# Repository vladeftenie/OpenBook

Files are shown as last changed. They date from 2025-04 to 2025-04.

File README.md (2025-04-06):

# OpenBook ESP32-C6 Complete Hardware Guide

## Overview
The OpenBook is an e-reader built around the ESP32-C6 chip. It uses an e-paper screen (like Kindle), has an SD card slot for books, can check room temperature and air quality, and has a battery that lasts a long time. It connects to Wi-Fi and Bluetooth so you can download books and update it.

## Main Parts

### Brain: ESP32-C6-WROOM-1-N8
- **What It Does**: Controls everything in the device
- **Architecture**: RISC-V (Single-Core)
- **Wireless**: Wi-Fi 6, Bluetooth 5 LE
- **Power Needs**: 3.3V
- **How It Talks**: SPI, I²C, UART, GPIO, USB

## Display Details

### E-Paper Screen
- **How It Connects**: SPI (shares wires with SD card)
- **Wires**:
  - Select Wire (EPD_CS): `GPIO 10`
  - Command Wire (EPD_DC): `GPIO 5`
  - Reset Wire: `GPIO 23`
  - Busy Signal: `GPIO 3`
  - Data Wires: shared with SD card
- **Screen Size**: 1404 × 1872 pixels (6.8")

## Memory Options

### SD Card Slot
- **How It Connects**: SPI
- **Wires**:
  - Select Wire (SS_SD): `GPIO 4`
  - Data Out (MOSI): `GPIO 7`
  - Data In (MISO): `GPIO 27`
  - Clock (SCK): `GPIO 6`
- **Space**: Works with cards up to 32GB

### Built-in Flash Memory (64MB)
- **How It Connects**: SPI (shared)
- **Wires**:
  - Select Wire (FLASH_CS): `GPIO 12`
  - Shared: `MOSI`, `MISO`, `SCK`
- **What It Stores**: System files, fonts, and some books
- **Chip Used**: W25Q512JVEIQ (Winbond)

## Power System

### Power Supply
- **Gets Power From**: USB-C (5V)
- **Gives Power At**: 3.3V using a voltage regulator
- **Battery**: 3.7V Li-Po, 2000mAh

### Charging System
- **What It Does**: Charges the Li-Po battery
- **Charging Speed**: 500mA
- **Chip Used**: MCP73831T-2ACI-OT (Microchip)

### Battery Monitor
- **What It Does**: Checks battery level and voltage
- **How It Connects**: I²C
- **Chip Used**: MAX17048G+T10 (Analog Devices)

### Backup Power
- **What It Does**: Keeps critical parts running during battery swaps
- **Part Used**: CPH3225A supercapacitor (Seiko)

## Sensors

### Air Quality Sensor – BME688
- **What It Measures**: Temperature, humidity, air pressure, gas levels
- **How It Connects**: I²C (shares wires with clock)
- **Power Needs**: 3.3V
- **Power Control Wire**: `GPIO 17`

### Clock Chip – DS3231SN
- **What It Does**: Keeps accurate time even when powered off
- **How It Connects**: I²C
- **Wires**:
  - Clock Wire (SCL): `GPIO 20`
  - Data Wire (SDA): `GPIO 19`
  - Alert Wire (INT): `GPIO 8`
  - Timing Wire (32KHz): `GPIO 9`
  - Reset Wire: `GPIO 16`
- **How Accurate**: About 1 minute off per year

## Connecting to Other Things

### USB-C Port
- **What It Does**: Charges the device and transfers data
- **Data Wires**:
  - USB_D-: `GPIO 13`
  - USB_D+: `GPIO 14`
- **Protection**: Has surge protection (USBLC6-2SC6Y chip)

### Expansion Port (Qwiic / Stemma QT)
- **What It Does**: Lets you add other sensors or devices
- **How It Connects**: I²C
- **Power Out**: 3.3V
- **Wires**: Uses the same I²C wires as other parts

## User Buttons
- **Boot Button**: Connected to `GPIO 15` (changes boot mode)
- **Reset Button**: Connected to pin 3 (restarts device)
- **Mode Button**: Connected to `GPIO 23` (changes display modes)

## Protection Features
- Surge protectors on USB and other wires
- Protection against putting batteries in backward
- Static electricity protection

## How Parts Connect

| Pin Number | What It Does | Connects To | More Info |
|---|---|---|---|
| 3 | RESET | Reset Button | Restarts the whole system |
| 4 | SS_SD | SD Card (pin 2) | Selects the SD card for talking |
| 6 | SCK | SD Card (pin 5) | Clock beat for data timing |
| 7 | MOSI | SD Card (pin 3) | Sends data out to SD card |
| 8 | INT_RTC | Clock Chip (pin 3) | Gets alerts from the clock |
| 9 | 32KHz | Clock Chip (pin 1) | Gets timing signal from clock |
| 13 | USB_D- | USB-C Port (pin 3) | USB negative data wire |
| 14 | USB_D+ | USB-C Port (pin 1) | USB positive data wire |
| 15 | IO/BOOT | Boot Button | Selects startup mode |
| 16 | RTC_RST | Clock Chip (pin 4) | Resets the clock chip |
| 17 | I2C_PW | Air Sensor (pins 6, 8, 2) | Controls power to air sensor |
| 19 | SDA | Multiple devices | Shared data wire for I²C |
| 20 | SCL | Multiple devices | Shared clock wire for I²C |
| 23 | IO/CHANGE | Mode Button | Changes display/device mode |
| 27 | MISO | SD Card (pin 7) | Gets data from SD card |

## How It All Connects
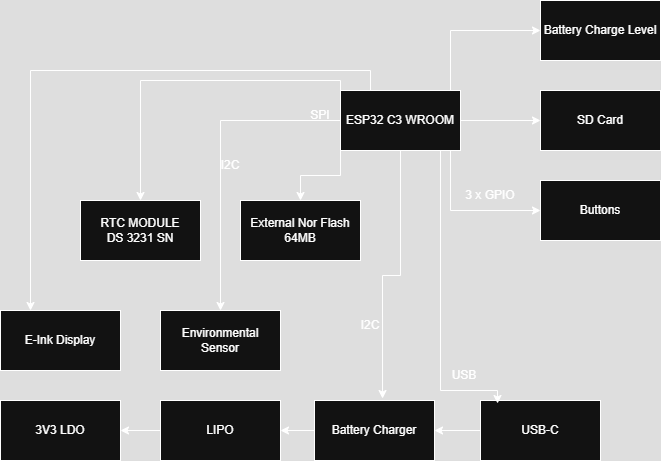
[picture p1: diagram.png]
Circuit Diagram


## BOM

| Component | Link | Estimated Price |
|---|---|---|
| R1_PINH1, R2-PINH1, R_BOOT, R_CHARGE, R_CL1, R_RESET | https://componentsearchengine.com/part-view/R0402%201%25%20100%20K%20(RC0402FR-07100KL)/YAGEO | €0.01 (per unit) |
| R1, R1-PINH, R2-PINH, R4, R5, R6, R7, R8, R9, R10 | https://componentsearchengine.com/part-view/R0402%201%25%20100%20K%20(RC0402FR-07100KL)/YAGEO | €0.01 (per unit) |
| C5 | https://componentsearchengine.com/part-view/CC0402MRX5R5BB106/YAGEO | €0.10 |
| EPD_C1, EPD_C2, EPD_C5, EPD_C6, EPD_C7, EPD_C8, EPD_C9, EPD_C10, EPD_C11, EPD_C12 | https://componentsearchengine.com/part-view/CC0402MRX5R5BB106/YAGEO | €0.10 (per unit) |
| R2 | https://componentsearchengine.com/part-view/R0402%201%25%20100%20K%20(RC0402FR-07100KL)/YAGEO | €0.01 |
| R1_BAT | https://componentsearchengine.com/part-view/R0402%201%25%20100%20K%20(RC0402FR-07100KL)/YAGEO | €0.01 |
| U4 | https://www.snapeda.com/api/url_track_click_mouser/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 | €3.80 |
| J2 | https://componentsearchengine.com/part-view/USB4110-GF-A/GCT%20(GLOBAL%20CONNECTOR%20TECHNOLOGY) | €0.95 |
| D1 | https://www.snapeda.com/parts/USBLC6-2SC6Y/STMicroelectronics/view-part/?ref=eda | €0.60 |
| U1 | https://www.snapeda.com/parts/W25Q512JVEIQ/Winbond+Electronics/view-part/?ref=eda | €4.20 |
| D3, D4, D5 | https://www.snapeda.com/api/url_track_click_mouser/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 | €0.40 (per unit) |
| D6, D8, D9, D10, D11, D12 | https://www.snapeda.com/api/url_track_click_mouser/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 | €0.30 (per unit) |
| J3 | https://www.digikey.ro/en/models/926710 | €1.05 |
| C1_BAT, C1_BAT1, C1_BAT2, C2_BAT, C5_USB | https://componentsearchengine.com/part-view/CC0402MRX5R5BB106/YAGEO | €0.10 (per unit) |
| C4 | https://componentsearchengine.com/part-view/CC0402MRX5R5BB106/YAGEO | €0.10 |
| R2-USB, R2-USB1 | https://componentsearchengine.com/part-view/R0402%201%25%20100%20K%20(RC0402FR-07100KL)/YAGEO | €0.01 (per unit) |
| C1, C2, C4_USB, C6, C7, C8, C9, C10, C_DELAY | https://componentsearchengine.com/part-view/CC0402MRX5R5BB106/YAGEO | €0.10 (per unit) |
| C3 | https://a360.co/4iZy6AA | €0.12 |
| J4 | https://store.comet.srl.ro/Catalogue/Product/43497/ | €0.35 |
| R_CAPACITOR | https://componentsearchengine.com/part-view/R0402%201%25%20100%20K%20(RC0402FR-07100KL)/YAGEO | €0.01 |
| R2_BAT | https://componentsearchengine.com/part-view/R0402%201%25%20100%20K%20(RC0402FR-07100KL)/YAGEO | €0.01 |
| TP1, TP2, TP3, TP4, TP5, TP6, TP7, TP8, TP9, TP10, TP11, TP12, TP13, TP14, TP15, TP16, TP17 | https://grabcad.com/library/test-points-printed-circuit-board-1 | €0.02 (per unit) |
| U2 | https://www.snapeda.com/parts/ESP32-C6-WROOM-1-N8/Espressif+Systems/view-part/?ref=eda | €4.50 |
| PFMF.050.1 | https://www.mouser.co.uk/ProductDetail/EPCOS-TDK/B72520T0350K062?qs=dEfas%2FXlABIszF52uu7vrg%3D%3D | €0.65 |
| CHG_LED | https://www.snapeda.com/parts/KP-1608SURCK/Kingbright/view-part/?ref=search&t=LED%200603 | €0.15 |
| SJ1 | https://grabcad.com/library/solder-jumpers-1 | €0.05 |
| SENSOR2 | https://www.snapeda.com/parts/BME680/Bosch/view-part/?welcome=home | €10.50 |
| MCP73831 | https://www.digikey.ro/en/products/detail/microchip-technology/MCP73831T-2ACI-OT/964301 | €0.75 |
| J1 | https://componentsearchengine.com/part-view/XC6220A331MR-G/Torex | €1.25 |
| R3 | https://componentsearchengine.com/part-view/R0402%201%25%20100%20K%20(RC0402FR-07100KL)/YAGEO | €0.01 |
| R1_PWRUSB | https://componentsearchengine.com/part-view/R0402%201%25%20100%20K%20(RC0402FR-07100KL)/YAGEO | €0.01 |
| IC4 | https://componentsearchengine.com/part-view/XC6220A331MR-G/Torex | €1.25 |
| L1 | https://eu.mouser.com/ProductDetail/Wurth-Elektronik/744043680?qs=PGXP4M47uW6VkZq%252BkzjrHA%3D%3D | €0.85 |
| IC1 | https://componentsearchengine.com/part-view/BD5229G-TR/ROHM%20Semiconductor | €1.20 |
| BOOT_BUTTON, CHANGE_BUTTON, RESET_BUTTON | https://www.snapeda.com/parts/EVQP7L01P/Panasonic/view-part/?ref=search&t=evqp7l | €0.25 (per unit) |
| C10_SUPERCAP | https://www.snapeda.com/api/url_track_click_mouser/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 | €2.50 |
| U3 | https://www.snapeda.com/api/url_track_click_mouser/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 | €8.95 |
| Q2 | https://componentsearchengine.com/part-view/DMG2305UX-7/Diodes%20Incorporated | €0.55 |
| Q1, Q3 | https://componentsearchengine.com/part-view/SI1308EDL-T1-GE3/Vishay | €0.45 (per unit) |
| D2, D7 | https://eu.mouser.com/ProductDetail/KYOCERA-AVX/SD0805S020S1R0?qs=jCA%252BPfw4LHbpkAoSnwrdjw%3D%3D | €0.30 (per unit) |

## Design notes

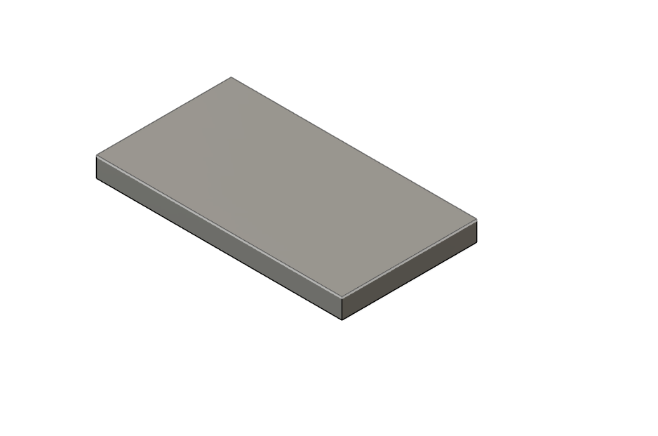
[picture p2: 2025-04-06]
Images/battery.png

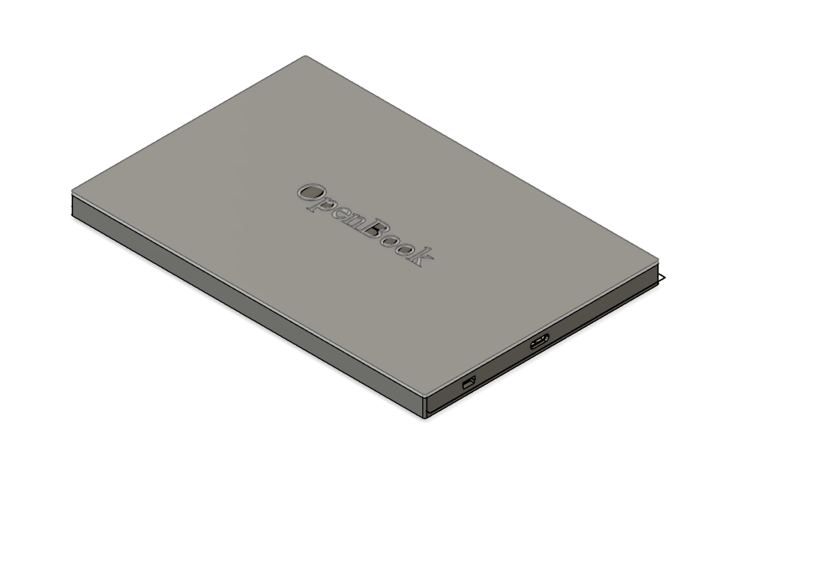
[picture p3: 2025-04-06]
Images/enclosure.png

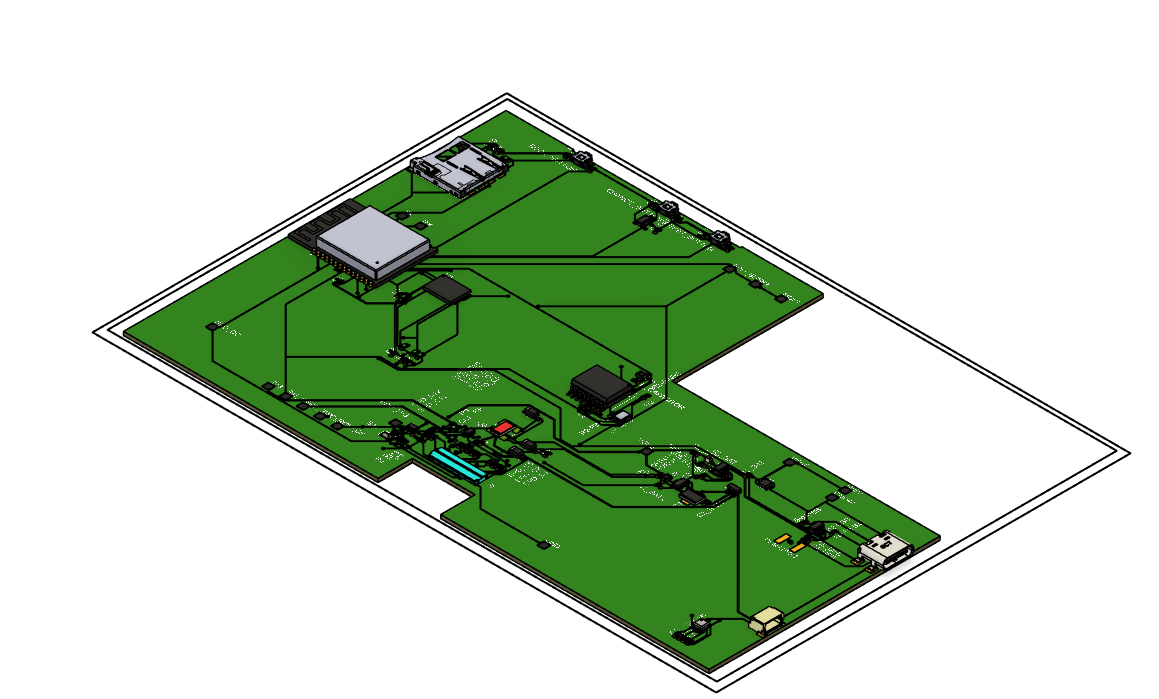
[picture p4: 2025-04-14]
Images/placuta.png

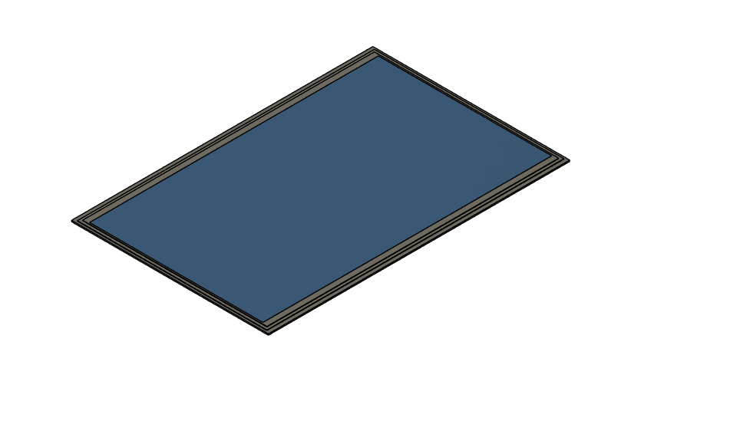
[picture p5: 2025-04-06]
Images/display.png

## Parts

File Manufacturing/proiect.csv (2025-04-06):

Qty | Value | Device | Package | Parts | Description | ARROW_PART_NUMBER | ARROW_PRICE-STOCK | AVAILABILITY | CENTROID_NOT_SPECIFIED | CHECK_PRICES | COPYRIGHT | DATASHEET | DESCRIPTION | DIGIKEY_DESCRIPTION | DIGIKEY_PART_NUMBER | HEIGHT | LEAD_FREE | MANUFACTURER_NAME | MANUFACTURER_PART_NUMBER | MF | MFR_NAME | MOUSER_PART_NUMBER | MOUSER_PRICE-STOCK | MOUSER_TESTING_PART_NUMBER | MOUSER_TESTING_PRICE-STOCK | MP | MPN | PACKAGE | POPULARITY | PREFIX | PRICE | PROD_ID | PURCHASE-URL | ROHS | SNAPEDA_LINK | SPICEMODEL | SPICEPREFIX | TEMPERATURE_RANGE_HIGH | TEMPERATURE_RANGE_LOW | TP_SIGNAL_NAME | VALUE
1 |  | ADAFRUIT_LEDCHIP-LED0603 | ADAFRUIT_CHIP-LED0603 | CHG_LED | LED
1 |  | SJ | SJ | SJ1 | SMD solder JUMPER |  |  |  |  |  |  |  |  |  |  |  |  |  |  |  |  |  |  |  |  |  |  |  | 3
1 | 0.1uF/50V | ESP32_WROVER_EAGLE-LTSPICE_CC0402 | ESP32_WROVER_EAGLE-LTSPICE_C0402 | EPD_C5 | CAPACITOR, European symbol |  |  |  |  |  |  |  |  |  |  |  |  |  |  |  |  |  |  |  |  |  |  |  |  |  |  |  |  |  |  | NONE | C
1 | 0.47 | ESP32_WROVER_EAGLE-LTSPICE_RR0402 | ESP32_WROVER_EAGLE-LTSPICE_R0402 | R3 | RESISTOR, European symbol |  |  |  |  |  |  |  |  |  |  |  |  |  |  |  |  |  |  |  |  |  |  |  |  |  |  |  |  |  |  | NONE | R
1 | 100k | ESP32_WROVER_EAGLE-LTSPICE_RR0402 | ESP32_WROVER_EAGLE-LTSPICE_R0402 | R1_PWRUSB | RESISTOR, European symbol |  |  |  |  |  |  |  |  |  |  |  |  |  |  |  |  |  |  |  |  |  |  |  |  |  |  |  |  |  |  | NONE | R
8 | 100nF | ESP32_WROVER_EAGLE-LTSPICE_CC0402 | ESP32_WROVER_EAGLE-LTSPICE_C0402 | C1, C2, C4_USB, C6, C8, C9, C10, C_DELAY | CAPACITOR, European symbol |  |  |  |  |  |  |  |  |  |  |  |  |  |  |  |  |  |  |  |  |  |  |  |  |  |  |  |  |  |  | NONE | C
1 | 100uF | RCL_CPOL-EUCT3528 | RCL_CT3528 | C3 | POLARIZED CAPACITOR, European symbol |  |  |  |  |  |  |  |  |  |  |  |  |  |  |  |  |  |  |  |  |  |  |  | 0 |  |  |  |  |  |  |  | C
16 | 10K | ESP32_WROVER_EAGLE-LTSPICE_RR0402 | ESP32_WROVER_EAGLE-LTSPICE_R0402 | R1, R1-PINH, R1-PINH1, R2-PINH, R2-PINH1, R4, R5, R6, R7, R8, R9, R10, R_BOOT, R_CHANGE, R_CL1, R_RESET | RESISTOR, European symbol |  |  |  |  |  |  |  |  |  |  |  |  |  |  |  |  |  |  |  |  |  |  |  |  |  |  |  |  |  |  | NONE | R
1 | 10uF | ESP32_WROVER_EAGLE-LTSPICE_CC0402 | ESP32_WROVER_EAGLE-LTSPICE_C0402 | C7 | CAPACITOR, European symbol |  |  |  |  |  |  |  |  |  |  |  |  |  |  |  |  |  |  |  |  |  |  |  |  |  |  |  |  |  |  | NONE | C
1 | 112A-TAAR-R03_ATTEND | 112A-TAAR-R03_ATTEND | 112ATAARR03ATTEND | J4 | Micro SD Card Socket, Push-Push Type, Top Mount, SMT, H=1.83mm, 10u |  |  |  |  |  |  |  | Micro SD Card Socket | Push-Push Type | Top Mount | SMT | H=1.83mm | 10u |  |  | 1.9mm |  | ATTEND | 112A-TAAR-R03 ATTEND
1 | 15 | ESP32_WROVER_EAGLE-LTSPICE_RR0402 | ESP32_WROVER_EAGLE-LTSPICE_R0402 | R_CAPACITOR | RESISTOR, European symbol |  |  |  |  |  |  |  |  |  |  |  |  |  |  |  |  |  |  |  |  |  |  |  |  |  |  |  |  |  |  | NONE | R
1 | 1uF | ESP32_WROVER_EAGLE-LTSPICE_CC0402 | ESP32_WROVER_EAGLE-LTSPICE_C0402 | C5 | CAPACITOR, European symbol |  |  |  |  |  |  |  |  |  |  |  |  |  |  |  |  |  |  |  |  |  |  |  |  |  |  |  |  |  |  | NONE | C
9 | 1uF/50V | ESP32_WROVER_EAGLE-LTSPICE_CC0402 | ESP32_WROVER_EAGLE-LTSPICE_C0402 | EPD_C1, EPD_C2, EPD_C6, EPD_C7, EPD_C8, EPD_C9, EPD_C10, EPD_C11, EPD_C12 | CAPACITOR, European symbol |  |  |  |  |  |  |  |  |  |  |  |  |  |  |  |  |  |  |  |  |  |  |  |  |  |  |  |  |  |  | NONE | C
1 | 2.2 | ESP32_WROVER_EAGLE-LTSPICE_RR0402 | ESP32_WROVER_EAGLE-LTSPICE_R0402 | R2 | RESISTOR, European symbol |  |  |  |  |  |  |  |  |  |  |  |  |  |  |  |  |  |  |  |  |  |  |  |  |  |  |  |  |  |  | NONE | R
1 | 200 | ESP32_WROVER_EAGLE-LTSPICE_RR0402 | ESP32_WROVER_EAGLE-LTSPICE_R0402 | R1_BAT | RESISTOR, European symbol |  |  |  |  |  |  |  |  |  |  |  |  |  |  |  |  |  |  |  |  |  |  |  |  |  |  |  |  |  |  | NONE | R
2 | 20V/4.2A/52mO/1.4W | ESP32_WROVER_SPARKFUN-DISCRETESEMI_MOSFET_PCH-DMG2305UX-7 | ESP32_WROVER_SPARKFUN-DISCRETESEMI_SOT23-3 | Q1, Q2 | P-channel MOSFETs |  |  |  |  |  |  |  |  |  |  |  |  |  |  |  |  |  |  |  |  |  |  |  |  |  |  | TRAN-14388 |  |  |  |  |  |  |  |  | 20V/4.2A/52mO/1.4W
1 | 2K | ESP32_WROVER_EAGLE-LTSPICE_RR0402 | ESP32_WROVER_EAGLE-LTSPICE_R0402 | R2_BAT | RESISTOR, European symbol |  |  |  |  |  |  |  |  |  |  |  |  |  |  |  |  |  |  |  |  |  |  |  |  |  |  |  |  |  |  | NONE | R
5 | 4.7uF | ESP32_WROVER_EAGLE-LTSPICE_CC0402 | ESP32_WROVER_EAGLE-LTSPICE_C0402 | C1_BAT, C1_BAT1, C1_BAT2, C2_BAT, C5_USB | CAPACITOR, European symbol |  |  |  |  |  |  |  |  |  |  |  |  |  |  |  |  |  |  |  |  |  |  |  |  |  |  |  |  |  |  | NONE | C
1 | 4.7uF/25V | ESP32_WROVER_EAGLE-LTSPICE_CC0402 | ESP32_WROVER_EAGLE-LTSPICE_C0402 | C4 | CAPACITOR, European symbol |  |  |  |  |  |  |  |  |  |  |  |  |  |  |  |  |  |  |  |  |  |  |  |  |  |  |  |  |  |  | NONE | C
2 | 5k1 | ESP32_WROVER_EAGLE-LTSPICE_RR0402 | ESP32_WROVER_EAGLE-LTSPICE_R0402 | R2-USB, R2-USB1 | RESISTOR, European symbol |  |  |  |  |  |  |  |  |  |  |  |  |  |  |  |  |  |  |  |  |  |  |  |  |  |  |  |  |  |  | NONE | R
1 | 68uH | 744043680IND_4828-WE-TPC_WRE | IND_4828-WE-TPC_WRE | L1 |  |  |  |  |  |  | Copyright (C) 2024 Ultra Librarian. All rights reserved. |  |  |  |  |  |  |  | 744043680 |  | Wurth Electronics
1 | BD5229G-TR | BD5229G-TR | SOT95P280X125-5N | IC1 | Voltage Detector with Adjustable Delay Time: CMOS processes are utilized to develop high precision, low current consumption CMOS reset ICs that allow arbitrary setting of the delay time. The extensive lineup includes both Nch Open Drain and CMOS output types in a wide range of detection voltages (from 2.3V to 6.0V, in 0.1V steps), enabling selection of the ideal solution based on customer requirements. In addition, the entire series is of course both lead-free and RoHS-compliant. |  |  |  |  |  |  |  | Voltage Detector with Adjustable Delay Time: CMOS processes are utilized to develop high precision | low current consumption CMOS reset ICs that allow arbitrary setting of the delay time. The extensive lineup includes both Nch Open Drain and CMOS output types in a wide range of detection voltages (from 2.3V to 6.0V | in 0.1V steps) | enabling selection of the ideal solution based on customer requirements. In addition | the entire series is of course both lead-free and RoHS-compliant. |  |  | 1.25mm |  | ROHM Semiconductor | BD5229G-TR |  |  | 755-BD5229G-TR | https://www.mouser.co.uk/ProductDetail/ROHM-Semiconductor/BD5229G-TR?qs=4kLU8WoGk0vvnhrrYwdszw%3D%3D
3 | BUTTON_CUSYOMV1 | BUTTON_CUSYOMV1 | MYBUTTON | BOOT_BUTTON, CHANGE_BUTTON, RESET_BUTTON
1 | CPH3225A | CPH3225A | CAPCP3225X100N | C10_SUPERCAP | Cap 0.011F 3.3V 1210 Flat Check availability |  |  | Not in stock |  | https://www.snapeda.com/parts/CPH3225A/Seiko+Instruments/view-part/?ref=eda |  |  | 11 mF (EDLC) Supercapacitor 3.3 V 1210 (3225 Metric) - - |  |  |  |  |  |  | Seiko Instruments |  |  |  |  |  | CPH3225A |  | 1210 Seiko |  |  | None |  | https://www.snapeda.com/api/url_track_click_mouser/?unipart_id=562593&manufacturer=Seiko Instruments&part_name=CPH3225A&search_term=None |  | https://www.snapeda.com/parts/CPH3225A/Seiko+Instruments/view-part/?ref=snap
1 | DS3231SN# | DS3231SN# | SOIC127P1032X265-16N | U3 | Real Time Clock Serial 16-Pin SOIC W T/R Check availability |  |  | In Stock |  | https://www.snapeda.com/parts/DS3231SN%23/Analog+Devices/view-part/?ref=eda |  |  | Extremely Accurate I²C-Integrated RTC/TCXO/Crystal |  |  |  |  |  |  | Analog Devices |  |  |  |  |  | DS3231SN# |  | SOIC-16 Maxim |  |  | None |  | https://www.snapeda.com/api/url_track_click_mouser/?unipart_id=99048&manufacturer=Analog Devices&part_name=DS3231SN#&search_term=None |  | https://www.snapeda.com/parts/DS3231SN%23/Analog+Devices/view-part/?ref=snap
1 | ESP32-C6-WROOM-1-N8 | ESP32-C6-WROOM-1-N8 | XCVR_ESP32-C6-WROOM-1-N8 | U2 | Check availability |  |  | In Stock |  | https://www.snapeda.com/parts/ESP32-C6-WROOM-1-N8/Espressif+Systems/view-part/?ref=eda |  |  | Multiprotocol Modules ESP32-C6 module | Wi-Fi 6 in 2.4 GHz band | Bluetooth 5 | Zigbee 3.0 and Thread. ESP34-WROOM Compatible - ENGINEERING SAMPLE |  |  |  |  |  |  | Espressif Systems |  |  |  |  |  | ESP32-C6-WROOM-1-N8 |  | None |  |  | None |  |  |  | https://www.snapeda.com/parts/ESP32-C6-WROOM-1-N8/Espressif+Systems/view-part/?ref=snap
1 | ESP32C6_VARISTORCN1812 | ESP32C6_VARISTORCN1812 | ESP32C6_VARISTOR_CT/CN1812 | PFMF.050.1 | VARISTOR |  |  |  |  |  |  |  |  |  |  |  |  |  |  |  |  |  |  |  |  |  |  |  | 0
2 | ESP32_WROVER_AVX---SD0805S020S1R0_AVX_SD0805S020S1R0_0_0AVX_SD0805S020S1R0_0_0 | ESP32_WROVER_AVX---SD0805S020S1R0_AVX_SD0805S020S1R0_0_0AVX_SD0805S020S1R0_0_0 | ESP32_WROVER_AVX---SD0805S020S1R0_AVX_SD0805S020S1R0_0 | D2, D7 | Schottky Barrier Rectifier Diode |  |  |  | No |  |  | http://datasheets.avx.com/schottky.pdf |  | DIODE SCHOTTKY 20V 1A 0805 | 478-7800-1-ND |  | yes |  |  | AVX |  | 581-SD0805S020S1R0 |  |  |  |  |  | 0805 (2012 metric) |  | D |  |  |  | yes |  |  |  | +125°C | -55°C
1 | ESP32_WROVER_BME680_BME680 | ESP32_WROVER_BME680_BME680 | ESP32_WROVER_BME680_PSON80P300X300X100-8N | SENSOR2 | Integrated Environmental Unit |  |  | Unavailable |  |  |  |  | Integrated Environmental Unit |  |  |  |  |  |  | Bosch Sensortec |  |  |  |  |  | BME680 |  | LGA-8 Bosch Tools |  |  | None
1 | ESP32_WROVER_SPARKFUN-IC-POWER_MCP73831 | ESP32_WROVER_SPARKFUN-IC-POWER_MCP73831 | ESP32_WROVER_SPARKFUN-IC-POWER_SOT23-5 | MCP73831 | MCP73831T Li-Ion, Li-Pol Controller |  |  |  |  |  |  |  |  |  |  |  |  |  |  |  |  |  |  |  |  |  |  |  |  |  |  | IC-09995
1 | FH34SRJ-24S-0.5SH_99_ | FH34SRJ-24S-0.5SH_99_ | FH34SRJ24S05SH99 | J1 | (0.50mm) Surface Mount, Right Angle |  |  |  |  |  |  |  | 24 Position FFC | FPC Connector Contacts | (0.50mm) Surface Mount | Right Angle |  |  | 1.1mm |  | Hirose | FH34SRJ-24S-0.5SH(99) |  |  | 798-FH34SRJ24S05SH99 | https://www.mouser.co.uk/ProductDetail/Hirose-Connector/FH34SRJ-24S-0.5SH99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
1 | MAX17048G+T10 | MAX17048G+T10 | SON50P200X200X80-9N | U4 | Check availability |  |  | In Stock |  | https://www.snapeda.com/parts/MAX17048G+T10/Analog+Devices/view-part/?ref=eda |  |  | 3µA 1-Cell/2-Cell Fuel Gauge with ModelGauge |  |  |  |  |  |  | Analog Devices |  |  |  |  |  | MAX17048G+T10 |  | TDFN-8 Maxim |  |  | None |  | https://www.snapeda.com/api/url_track_click_mouser/?unipart_id=329239&manufacturer=Analog Devices&part_name=MAX17048G+T10&search_term=None |  | https://www.snapeda.com/parts/MAX17048G+T10/Analog+Devices/view-part/?ref=snap
3 | MBR0530 | MBR0530 | SOD3716X135N | D3, D4, D5 | ON SEMICONDUCTOR - MBR0530 - DIODE, SCHOTTKY, 0.5A, 30V, SOD-123 |  |  | In Stock |  | https://www.snapeda.com/parts/MBR0530/Onsemi/view-part/?ref=eda |  |  | Diode Schottky 30 V 500mA Surface Mount SOD-123 |  |  |  |  |  |  | ON Semiconductor |  |  |  |  |  | MBR0530 |  | SOD-123-2 ON Semiconductor |  |  | None |  | https://www.snapeda.com/api/url_track_click_mouser/?unipart_id=179458&manufacturer=ON Semiconductor&part_name=MBR0530&search_term=None |  | https://www.snapeda.com/parts/MBR0530/Onsemi/view-part/?ref=snap
6 | PGB1010603MR | PGB1010603MR | DIOC1608X36N | D6, D8, D9, D10, D11, D12 | Check availability |  |  | In Stock |  | https://www.snapeda.com/parts/PGB1010603MR/Littelfuse/view-part/?ref=eda |  |  | 150V (Typ) Clamp - Ipp Tvs Diode Surface Mount 0603 (1608 Metric) |  |  |  |  |  |  | Littelfuse Inc. |  |  |  |  |  | PGB1010603MR |  | 0603 Littelfuse Inc. |  |  | None |  | https://www.snapeda.com/api/url_track_click_mouser/?unipart_id=5659453&manufacturer=Littelfuse Inc.&part_name=PGB1010603MR&search_term=None |  | https://www.snapeda.com/parts/PGB1010603MR/Littelfuse/view-part/?ref=snap
1 | QWIIC_RIGHT_ANGLE | QWIIC_CONNECTORJS-1MM | JST04_1MM_RA | J3 | SparkFun I2C Standard Qwiic Connector |  |  |  |  |  |  |  |  |  |  |  |  |  |  |  |  |  |  |  |  |  |  |  |  |  |  | CONN-13694 |  |  |  |  |  |  |  |  | QWIIC_RIGHT_ANGLE
1 | SAMACSYS_PARTS_USB4110-GF-A | SAMACSYS_PARTS_USB4110-GF-A | SAMACSYS_PARTS_USB4110GFA | J2 | CONN USB 2.0 TYPE-C R/A SMT |  |  |  |  |  |  |  | CONN USB 2.0 TYPE-C R/A SMT |  |  | 3.26mm |  | GCT (GLOBAL CONNECTOR TECHNOLOGY) | USB4110-GF-A |  |  | 640-USB4110-GF-A | https://www.mouser.co.uk/ProductDetail/GCT/USB4110-GF-A?qs=KUoIvG%2F9IlYiZvIXQjyJeA%3D%3D
1 | SI1308EDL-T1-GE3 | SI1308EDL-T1-GE3 | SOT65P210X110-3N | Q3 | MOSFET N-Ch 30V 1.5A TrenchFET SC70 Vishay Si1308EDL-T1-GE3 N-channel MOSFET Transistor, 1.5 A, 30 V, 3-Pin SC-70 |  |  | In Stock |  | https://www.snapeda.com/parts/SI1308EDL-T1-GE3/Vishay+Siliconix/view-part/?ref=eda |  |  | Si1308EDL-T1-GE3 N-channel MOSFET Transistor | 1.5 A | 30 V | 3-Pin SC-70 | Siliconix / Vishay SI1308EDL-T1-GE3 |  |  |  |  |  |  | Vishay Siliconix |  |  |  |  |  | SI1308EDL-T1-GE3 |  | SOT-323 Vishay Semiconductor |  |  | None |  | https://www.snapeda.com/api/url_track_click_mouser/?unipart_id=274603&manufacturer=Vishay Siliconix&part_name=SI1308EDL-T1-GE3&search_term=None |  | https://www.snapeda.com/parts/SI1308EDL-T1-GE3/Vishay+Siliconix/view-part/?ref=snap
17 | TPTP20R | TPTP20R | TP20R | TP1, TP2, TP3, TP4, TP5, TP6, TP7, TP8, TP9, TP10, TP11, TP12, TP13, TP14, TP15, TP16, TP17 | Test pad |  |  |  |  |  |  |  |  |  |  |  |  |  |  |  |  |  |  |  |  |  |  |  | 2
1 | USBLC6-2SC6Y | USBLC6-2SC6Y | SOT95P280X145-6N | D1 | Low Cap. ESD Protection Auto SOT-23-6 STMicroelectronics USBLC6-2SC6Y, Dual Uni-Directional TVS Diode Array, 6-Pin SOT-23 |  |  | In Stock |  | https://www.snapeda.com/parts/USBLC6-2SC6Y/STMicroelectronics/view-part/?ref=eda |  |  | 17V Clamp 5A (8/20µs) Ipp Tvs Diode Surface Mount SOT-23-6 |  |  |  |  |  |  | STMicroelectronics |  |  |  |  |  | USBLC6-2SC6Y |  | SOT-23-6 STMicroelectronics |  |  | None |  |  |  | https://www.snapeda.com/parts/USBLC6-2SC6Y/STMicroelectronics/view-part/?ref=snap
1 | W25Q512JVEIQ | W25Q512JVEIQ | SON127P600X800X80-9N | U1 | Check availability |  |  | In Stock |  | https://www.snapeda.com/parts/W25Q512JVEIQ/Winbond+Electronics/view-part/?ref=eda |  |  | FLASH - NOR Memory IC 512Mb (64M x 8) SPI - Quad I/O 133 MHz 8-WSON (8x6) |  |  |  |  |  |  | Winbond Electronics |  |  |  |  |  | W25Q512JVEIQ |  | Package |  |  | None |  |  |  | https://www.snapeda.com/parts/W25Q512JVEIQ/Winbond+Electronics/view-part/?ref=snap
1 | XC6220A331MR-G | XC6220A331MR-G | SOT95P280X120-5N | IC4 | LDO Voltage Regulators |  |  |  |  |  |  |  | LDO Voltage Regulators |  |  | 1.2mm |  | Torex | XC6220A331MR-G |  |  | 865-XC6220A331MR-G | https://www.mouser.co.uk/ProductDetail/Torex-Semiconductor/XC6220A331MR-G?qs=AsjdqWjXhJ8ZSWznL1J0gg%3D%3D

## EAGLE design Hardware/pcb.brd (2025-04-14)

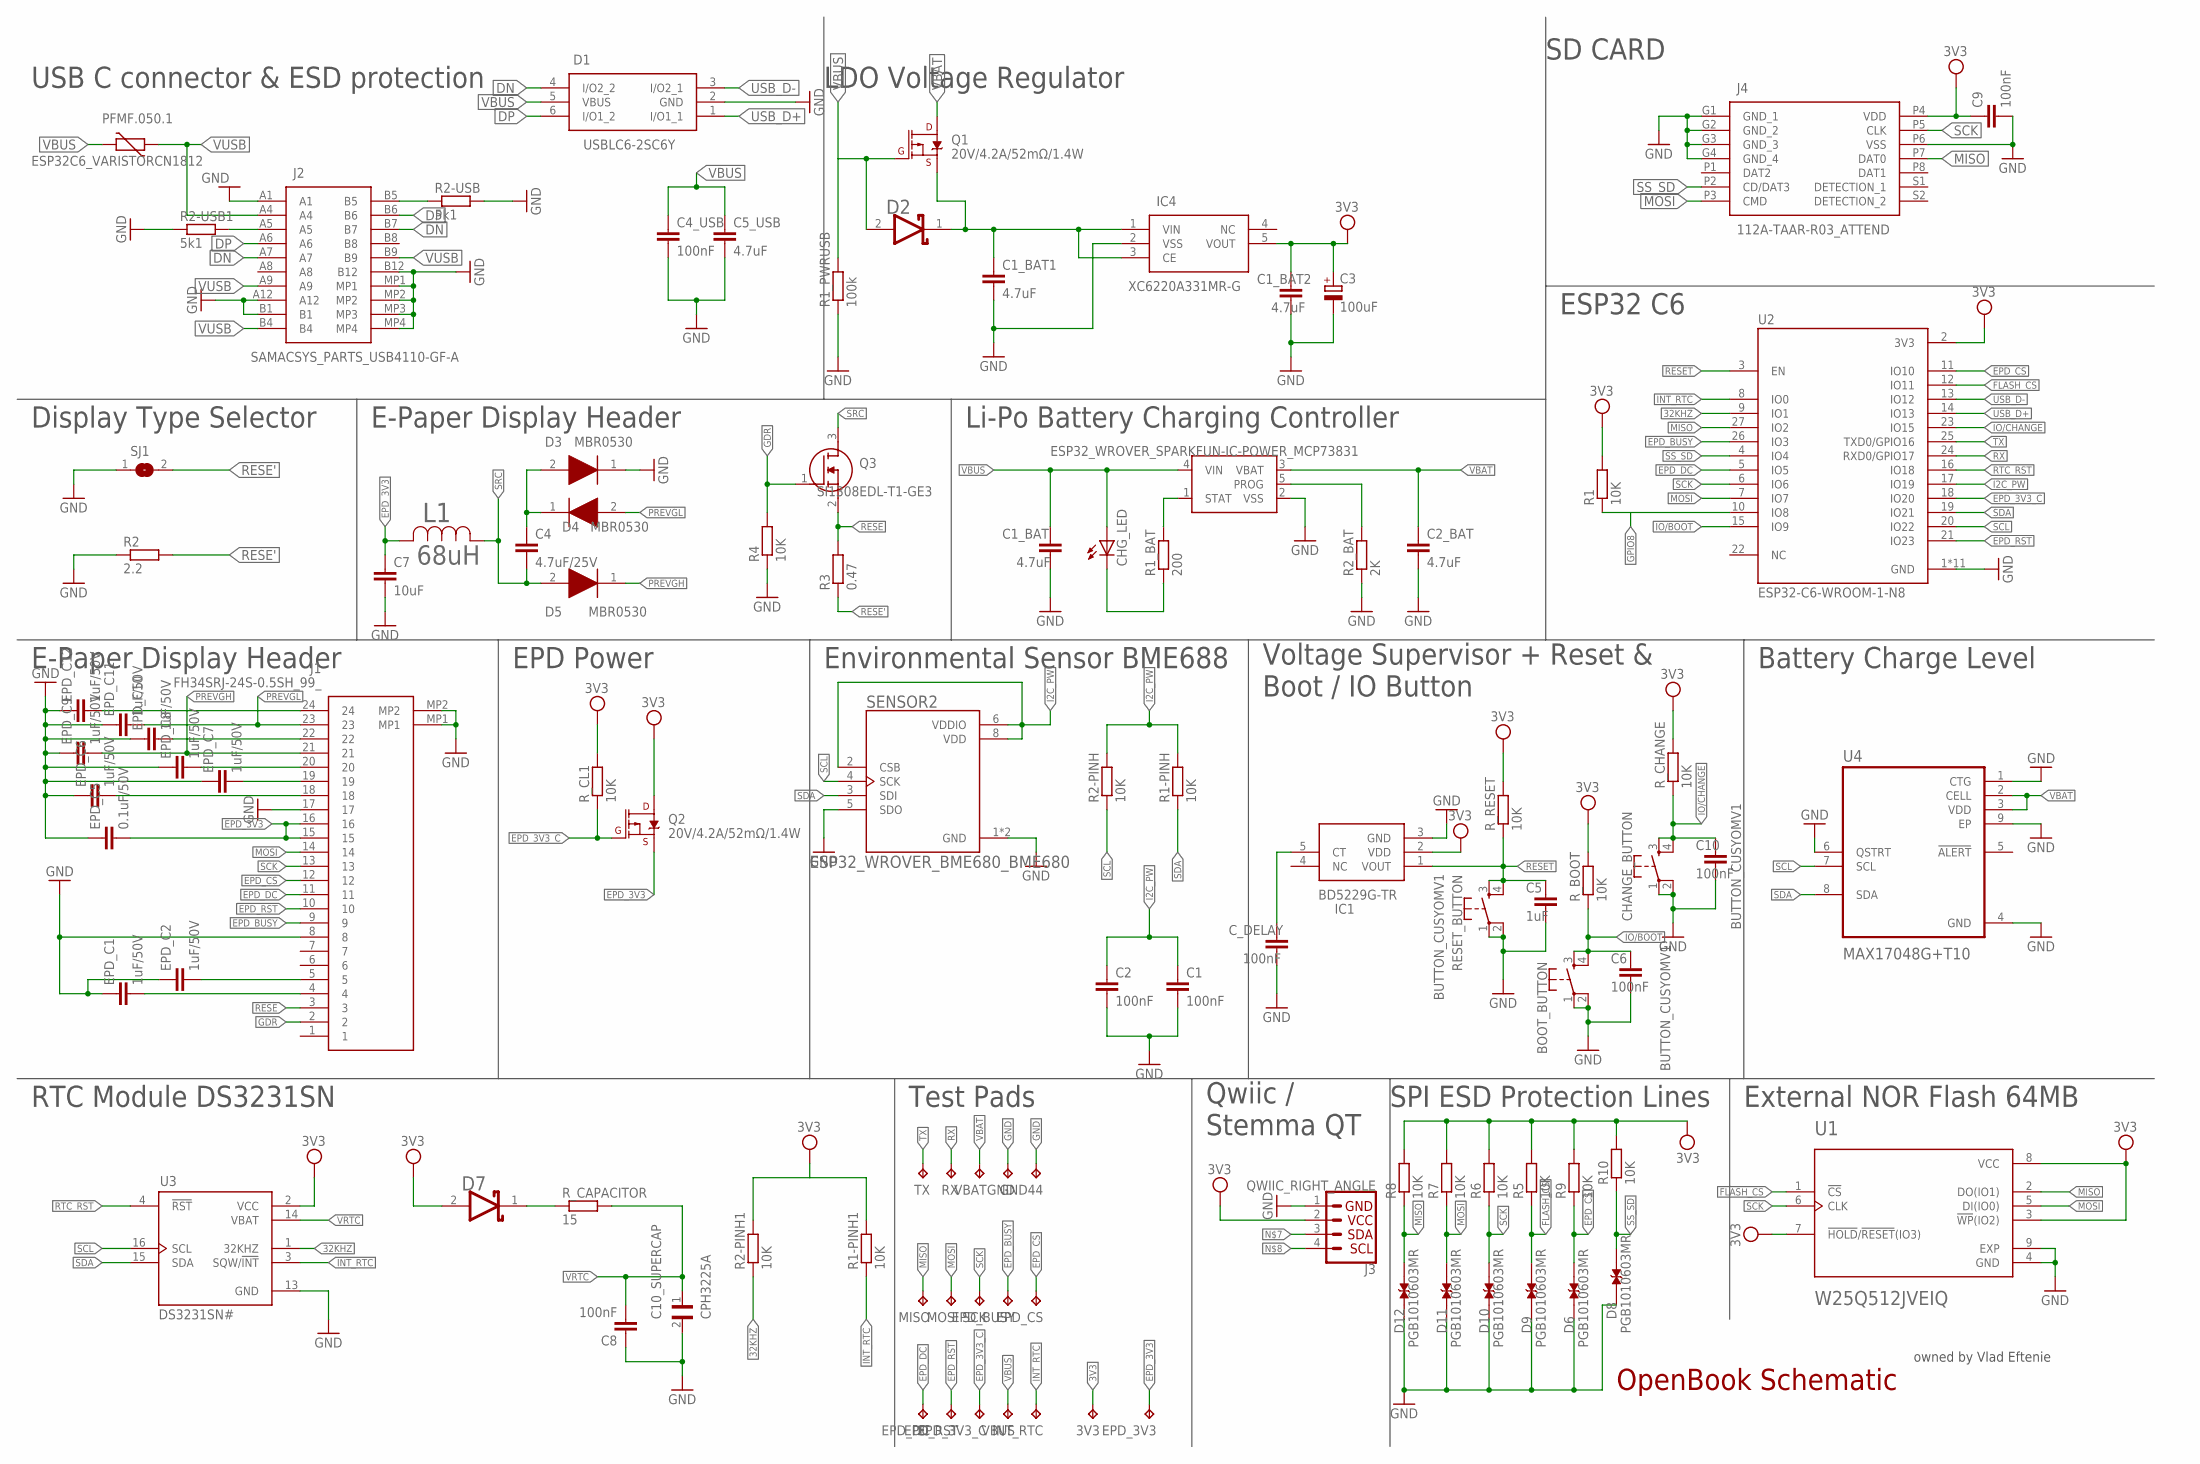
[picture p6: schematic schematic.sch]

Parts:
3V3: TPTP20R; TP20R
BOOT_BUTTON: BUTTON_CUSYOMV1; MYBUTTON
C1, C2, C4_USB, C6, C8, C9, C10: 100nF; ESP32_WROVER_EAGLE-LTSPICE_C0402
C1_BAT, C1_BAT1, C1_BAT2, C2_BAT, C5_USB: 4.7uF; ESP32_WROVER_EAGLE-LTSPICE_C0402
C3: 100uF; RCL_CT3528
C4: 4.7uF/25V; ESP32_WROVER_EAGLE-LTSPICE_C0402
C5: 1uF; ESP32_WROVER_EAGLE-LTSPICE_C0402
C7: 10uF; ESP32_WROVER_EAGLE-LTSPICE_C0402
C10_SUPERCAP: CPH3225A; CAPCP3225X100N
CHANGE_BUTTON: BUTTON_CUSYOMV1; MYBUTTON
CHG_LED: ADAFRUIT_LEDCHIP-LED0603; ADAFRUIT_CHIP-LED0603
C_DELAY: 100nF; ESP32_WROVER_EAGLE-LTSPICE_C0402
D1: USBLC6-2SC6Y; SOT95P280X145-6N
D2, D7: ESP32_WROVER_AVX---SD0805S020S1R0_AVX_SD0805S020S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; ESP32_WROVER_AVX---SD0805S020S1R0_AVX_SD0805S020S1R0_0
D3, D4, D5: MBR0530; SOD3716X135N
D6, D8, D9, D10, D11, D12: PGB1010603MR; DIOC1608X36N
EPD_3V3, EPD_3V3_C: TPTP20R; TP20R
EPD_BUSY: TPTP20R; TP20R
EPD_C1, EPD_C2, EPD_C6, EPD_C7, EPD_C8, EPD_C9, EPD_C10, EPD_C11, EPD_C12: 1uF/50V; ESP32_WROVER_EAGLE-LTSPICE_C0402
EPD_C5: 0.1uF/50V; ESP32_WROVER_EAGLE-LTSPICE_C0402
EPD_CS: TPTP20R; TP20R
EPD_DC: TPTP20R; TP20R
EPD_RST: TPTP20R; TP20R
GND, GND44: TPTP20R; TP20R
IC1: BD5229G-TR; SOT95P280X125-5N
IC4: XC6220A331MR-G; SOT95P280X120-5N
INT_RTC: TPTP20R; TP20R
J1: FH34SRJ-24S-0.5SH_99_; FH34SRJ24S05SH99
J2: SAMACSYS_PARTS_USB4110-GF-A; SAMACSYS_PARTS_USB4110GFA
J3: QWIIC_RIGHT_ANGLE; JST04_1MM_RA
J4: 112A-TAAR-R03_ATTEND; 112ATAARR03ATTEND
L1: 68uH; IND_4828-WE-TPC_WRE
MCP73831: ESP32_WROVER_SPARKFUN-IC-POWER_MCP73831; ESP32_WROVER_SPARKFUN-IC-POWER_SOT23-5
MISO: TPTP20R; TP20R
MOSI: TPTP20R; TP20R
PFMF.050.1: ESP32C6_VARISTORCN1812; ESP32C6_VARISTOR_CT/CN1812
Q1, Q2: 20V/4.2A/52mΩ/1.4W; ESP32_WROVER_SPARKFUN-DISCRETESEMI_SOT23-3
Q3: SI1308EDL-T1-GE3; SOT65P210X110-3N
R1, R1-PINH, R1-PINH1, R2-PINH, R2-PINH1, R4, R5, R6, R7, R8, R9, R10: 10K; ESP32_WROVER_EAGLE-LTSPICE_R0402
R1_BAT: 200; ESP32_WROVER_EAGLE-LTSPICE_R0402
R1_PWRUSB: 100k; ESP32_WROVER_EAGLE-LTSPICE_R0402
R2: 2.2; ESP32_WROVER_EAGLE-LTSPICE_R0402
R2-USB, R2-USB1: 5k1; ESP32_WROVER_EAGLE-LTSPICE_R0402
R2_BAT: 2K; ESP32_WROVER_EAGLE-LTSPICE_R0402
R3: 0.47; ESP32_WROVER_EAGLE-LTSPICE_R0402
RESET_BUTTON: BUTTON_CUSYOMV1; MYBUTTON
RX: TPTP20R; TP20R
R_BOOT: 10K; ESP32_WROVER_EAGLE-LTSPICE_R0402
R_CAPACITOR: 15; ESP32_WROVER_EAGLE-LTSPICE_R0402
R_CHANGE: 10K; ESP32_WROVER_EAGLE-LTSPICE_R0402
R_CL1: 10K; ESP32_WROVER_EAGLE-LTSPICE_R0402
R_RESET: 10K; ESP32_WROVER_EAGLE-LTSPICE_R0402
SCK: TPTP20R; TP20R
SENSOR2: ESP32_WROVER_BME680_BME680; ESP32_WROVER_BME680_PSON80P300X300X100-8N
SJ1: SJ
TX: TPTP20R; TP20R
U1: W25Q512JVEIQ; SON127P600X800X80-9N
U2: ESP32-C6-WROOM-1-N8; XCVR_ESP32-C6-WROOM-1-N8
U3: DS3231SN#; SOIC127P1032X265-16N
U4: MAX17048G+T10; SON50P200X200X80-9N
VBAT: TPTP20R; TP20R
VBUS: TPTP20R; TP20R

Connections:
3V3: 3V3.TP, C1_BAT2.1, C3.+, C9.1, D7.2 (ANODE), IC1.2 (VDD), IC4.5 (VOUT), J3.2, J4.P4 (VDD), Q2.3 (D), R1.2, R5.2, R6.2, R7.2, R8.2, R9.2, R10.2, R_BOOT.2, R_CHANGE.2, R_CL1.2, R_RESET.2, U1.3 (!WP!(IO2)), U1.7 (!HOLD!/!RESET!(IO3)), U1.8 (VCC), U2.2 (3V3), U3.2 (VCC)
32KHZ: R2-PINH1.1, U2.9 (IO1), U3.1 (32KHZ)
DN: D1.4 (I/O2_2), J2.A7, J2.B7
DP: D1.6 (I/O1_2), J2.A6, J2.B6
EPD_3V3: C7.1, EPD_3V3.TP, EPD_C5.2, J1.15, J1.16, L1.2, Q2.2 (S)
EPD_3V3_C: EPD_3V3_C.TP, Q2.1 (G), R_CL1.1, U2.18 (IO20)
EPD_BUSY: EPD_BUSY.TP, J1.9, U2.26 (IO3)
EPD_CS: D6.2, EPD_CS.TP, J1.12, R9.1, U2.11 (IO10)
EPD_DC: EPD_DC.TP, J1.11, U2.5 (IO5)
EPD_RST: EPD_RST.TP, J1.10, U2.21 (IO23)
FLASH_CS: D9.2, R5.1, U1.1 (!CS), U2.12 (IO11)
GDR: J1.2, Q3.1 (G), R4.2
GND: BOOT_BUTTON.1, BOOT_BUTTON.2, C1.2, C1_BAT.2, C1_BAT1.2, C1_BAT2.2, C2.2, C2_BAT.2, C3.-, C4_USB.2, C5.2, C5_USB.2, C6.2, C7.2, C8.1, C9.2, C10.2, C10_SUPERCAP.2, CHANGE_BUTTON.1, CHANGE_BUTTON.2, C_DELAY.2, D1.2 (GND), D3.1 (K), D6.1, D8.1, D9.1, D10.1, D11.1, D12.1, EPD_C1.1, EPD_C2.1, EPD_C5.1, EPD_C6.1, EPD_C7.1, EPD_C8.1, EPD_C9.1, EPD_C10.1, EPD_C11.1, EPD_C12.1, GND.TP, GND44.TP, IC1.3 (GND), IC4.2 (VSS), J1.8, J1.17, J1.MP1, J1.MP2, J2.A1, J2.A12, J2.B1, J2.B12, J2.MP1, J2.MP2, J2.MP3, J2.MP4, J3.1, J4.G1 (GND_1), J4.G2 (GND_2), J4.G3 (GND_3), J4.G4 (GND_4), J4.P6 (VSS), MCP73831.2 (VSS), R1_PWRUSB.1, R2.1, R2-USB.2, R2-USB1.1, R2_BAT.1, R4.1, RESET_BUTTON.1, RESET_BUTTON.2, SENSOR2.1 (GND), SENSOR2.5 (SDO), SENSOR2.7 (GND), SJ1.1, U1.4 (GND), U1.9 (EXP), U2.1 (GND), U2.28 (GND), U2.29_1 (GND), U2.29_2 (GND), U2.29_3 (GND), U2.29_4 (GND), U2.29_5 (GND), U2.29_6 (GND), U2.29_7 (GND), U2.29_8 (GND), U2.29_9 (GND), U3.13 (GND), U4.1 (CTG), U4.4 (GND), U4.6 (QSTRT), U4.9 (EP)
I2C_PW: C1.1, C2.1, R1-PINH.2, R2-PINH.2, SENSOR2.2 (CSB), SENSOR2.6 (VDDIO), SENSOR2.8 (VDD), U2.17 (IO19)
INT_RTC: INT_RTC.TP, R1-PINH1.1, U2.8 (IO0), U3.3 (SQW/!INT)
IO/BOOT: BOOT_BUTTON.3, BOOT_BUTTON.4, C6.1, R_BOOT.1, U2.15 (IO9)
IO/CHANGE: C10.1, CHANGE_BUTTON.3, CHANGE_BUTTON.4, R_CHANGE.1, U2.23 (IO15)
MISO: D12.2, J4.P7 (DAT0), MISO.TP, R8.1, U1.2 (DO(IO1)), U2.27 (IO2)
MOSI: D11.2, J1.14, J4.P3 (CMD), MOSI.TP, R7.1, U1.5 (DI(IO0)), U2.7 (IO7)
unnamed: J2.A5, R2-USB1.2
unnamed: J2.B5, R2-USB.1
unnamed: D2.2 (ANODE), Q1.1 (G)
unnamed: R1.1, U2.10 (IO8)
unnamed: C1_BAT1.1, D2.1 (CATHODE), IC4.1 (VIN), IC4.3 (CE), Q1.2 (S)
unnamed: C4.1, D3.2 (A), D4.1 (K)
unnamed: MCP73831.1 (STAT), R1_BAT.2
unnamed: MCP73831.5 (PROG), R2_BAT.2
unnamed: C_DELAY.1, IC1.5 (CT)
unnamed: EPD_C12.2, J1.24
unnamed: R1-PINH1.2, R2-PINH1.2
unnamed: CHG_LED.C, R1_BAT.1
unnamed: EPD_C10.2, J1.22
unnamed: D7.1 (CATHODE), R_CAPACITOR.1
unnamed: EPD_C8.2, J1.20
unnamed: EPD_C7.2, J1.19
unnamed: EPD_C6.2, J1.18
unnamed: EPD_C1.2, J1.4
unnamed: EPD_C2.2, J1.5
PREVGH: D5.1 (K), EPD_C9.2, J1.21
PREVGL: D4.2 (A), EPD_C11.2, J1.23
RESE: J1.3, Q3.2 (S), R3.2
RESE': R2.2, R3.1, SJ1.2
RESET: C5.1, IC1.1 (VOUT), RESET_BUTTON.3, RESET_BUTTON.4, R_RESET.1, U2.3 (EN)
RTC_RST: U2.16 (IO18), U3.4 (!RST)
RX: RX.TP, U2.24 (RXD0/GPIO17)
SCK: D10.2, J1.13, J4.P5 (CLK), R6.1, SCK.TP, U1.6 (CLK), U2.6 (IO6)
SCL: R2-PINH.1, SENSOR2.4 (SCK), U2.20 (IO22), U3.16 (SCL), U4.7 (SCL)
SDA: R1-PINH.1, SENSOR2.3 (SDI), U2.19 (IO21), U3.15 (SDA), U4.8 (SDA)
SRC: C4.2, D5.2 (A), L1.1, Q3.3 (D)
SS_SD: D8.2, J4.P2 (CD/DAT3), R10.1, U2.4 (IO4)
TX: TX.TP, U2.25 (TXD0/GPIO16)
USB_D+: D1.1 (I/O1_1), U2.14 (IO13)
USB_D-: D1.3 (I/O2_1), U2.13 (IO12)
VBAT: C2_BAT.1, MCP73831.3 (VBAT), Q1.3 (D), U4.2 (CELL), U4.3 (VDD), VBAT.TP
VBUS: C1_BAT.1, C4_USB.1, C5_USB.1, CHG_LED.A, D1.5 (VBUS), MCP73831.4 (VIN), PFMF.050.1.2, R1_PWRUSB.2, VBUS.TP
VRTC: C8.2, C10_SUPERCAP.1, R_CAPACITOR.2, U3.14 (VBAT)
VUSB: J2.A4, J2.A9, J2.B4, J2.B9, PFMF.050.1.1

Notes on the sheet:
owned by Vlad Eftenie
USB C connector & ESD protection
LDO Voltage Regulator
SD CARD
Display Type Selector
E-Paper Display Header
Li-Po Battery Charging Controller
ESP32 C6
EPD Power
Environmental Sensor BME688
Voltage Supervisor + Reset & Boot / IO Button
Battery Charge Level
RTC Module DS3231SN
Test Pads
Qwiic / Stemma QT
SPI ESD Protection Lines
OpenBook Schematic
External NOR Flash 64MB

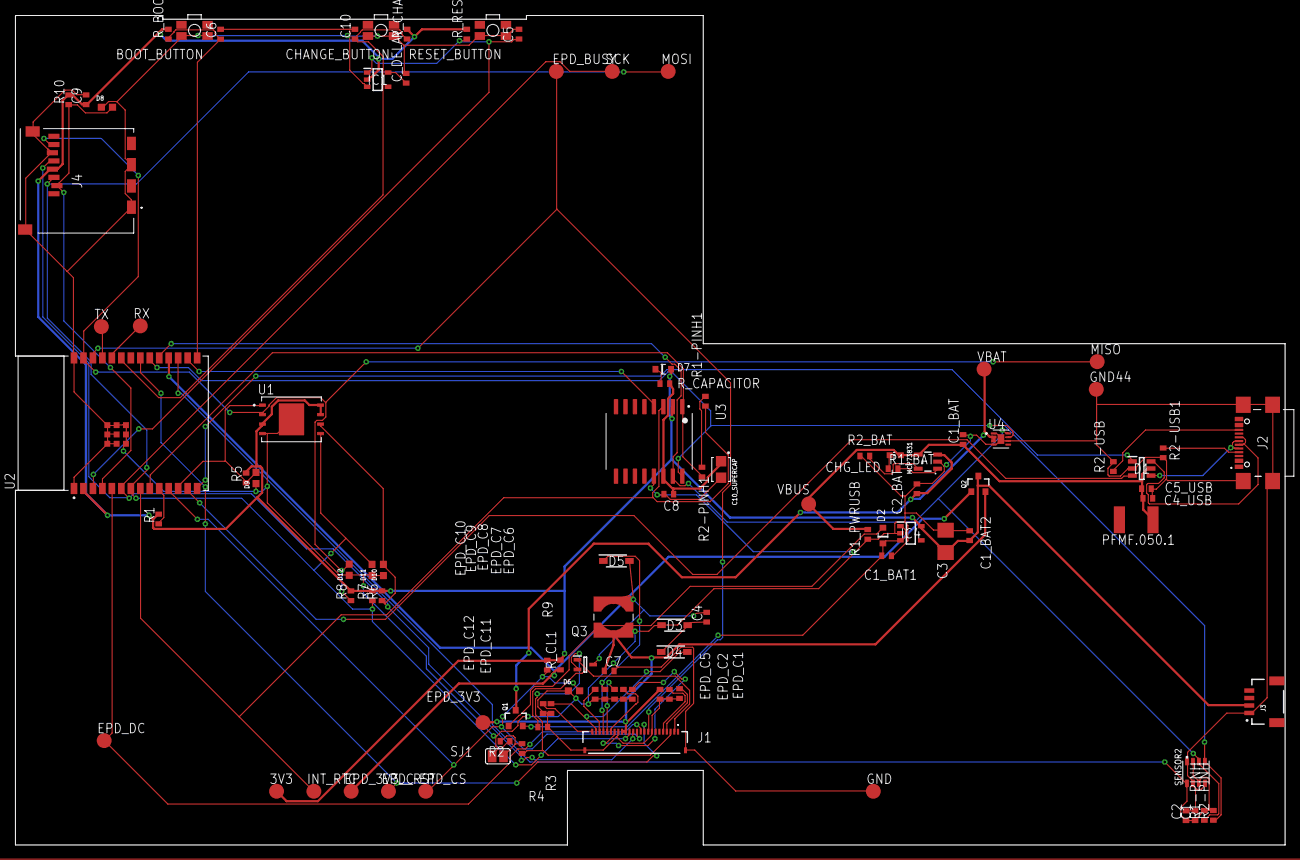
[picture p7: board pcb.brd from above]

Board: 2 copper layers, 170.2 x 111.2 mm, 103 parts (0 on the bottom side), 57 nets.

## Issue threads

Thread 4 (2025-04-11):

[PCB]There are traces routed too close to component pads, which may cause soldering issues.

awy23, 2025-04-11:

Closed 2025-04-14.

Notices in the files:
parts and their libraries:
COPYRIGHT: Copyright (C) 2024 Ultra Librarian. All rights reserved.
